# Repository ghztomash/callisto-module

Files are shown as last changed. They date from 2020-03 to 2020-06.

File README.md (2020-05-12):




# callisto-module
Callisto Eurorack Module.

A Teensy 3.2 based eurorack audio synth module.
Although the original idea was a Drum Synthesis module, the hardware is designed in a general way to support any audio synthesis firmware using the Teensy Audio Library.

A Hardware Abstraction Library is provided to simplify reading of the hardware peripherals.

## Features
* 1 x Trigger input with LED.
* 1 x CV 1 V/Oct input.
* 5 x -5 to +5 V CV inputs.
* 1 x 12bit DAC output.
* 6 x Potentiometers.
* 2 x Mode buttons with 3 LEDs each.

## Specs
* 10 HP Width
* 0.068% THD @ 100 Hz (But loads of noise from DSP ;))
* 9.6 Vpp output.
* +12V: 80 mA, -12V: 7 mA, +5V: 0 mA

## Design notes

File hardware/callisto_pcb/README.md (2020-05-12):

# callisto-module hardware
Callisto Eurorack module PCB Altium Designer files.
For Gerbers, schematics and BOM refer to the [Wiki](https://github.com/ghztomash/callisto-module/wiki) and [Release](https://github.com/ghztomash/callisto-module/releases) pages.

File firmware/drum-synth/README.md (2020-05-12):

### Drum voice synthesizer Firmware

Callisto Drum synthesizer, featuring 3 modes for kick, snare and hat sounds. With 3 waveforms each.

#### Parameters
* Pitch.
* Decay.
* Modulation Depth, bipolar, left envelope, right LFO.
* Modulation Rate, Envelope decay and LFO speed.
* DJ style filter, bipolar low-pass and high-pass.
* Overdrive.
* Instrument Select mode.
* Waveform Select mode.

#### Layout
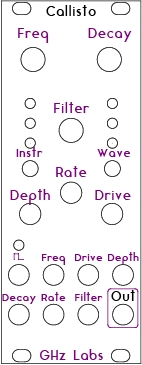
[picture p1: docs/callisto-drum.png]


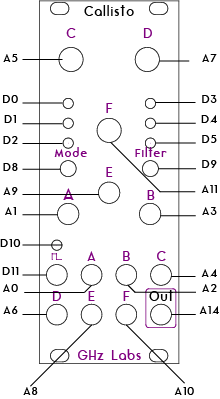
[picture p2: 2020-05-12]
docs/callisto-pinout.png

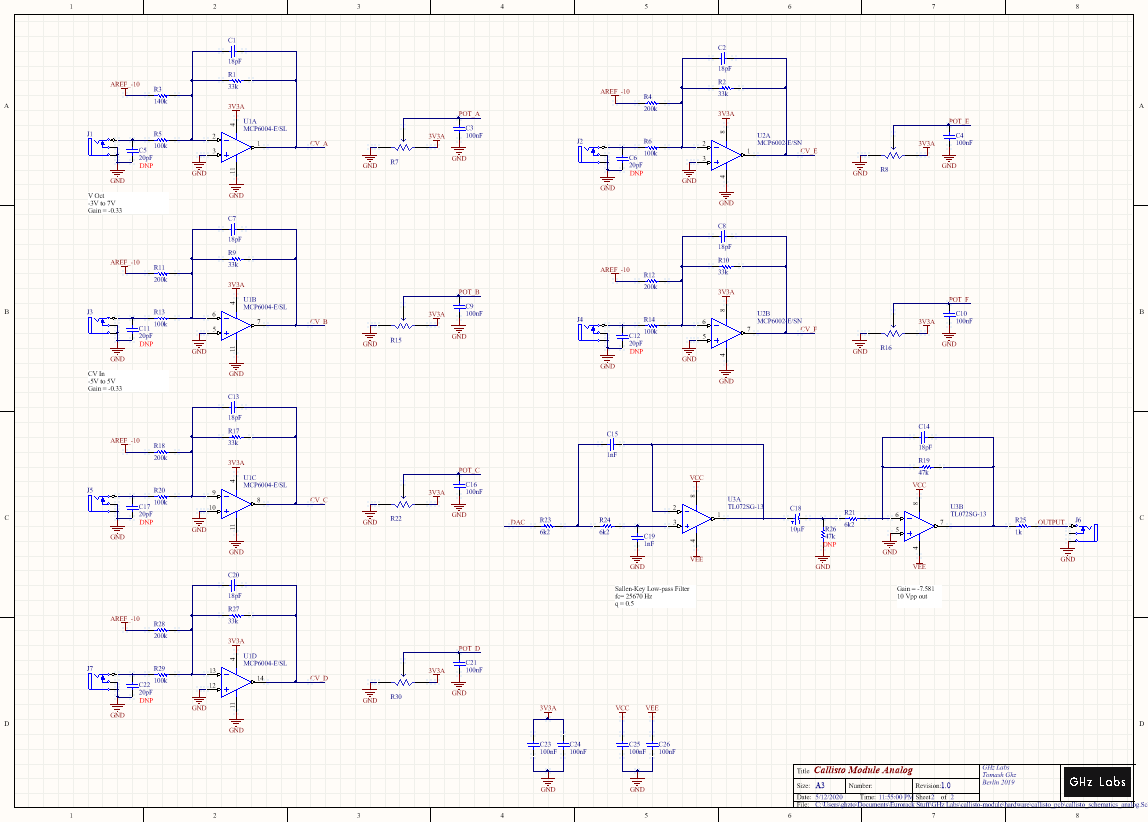
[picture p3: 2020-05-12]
docs/callisto-schematics.png

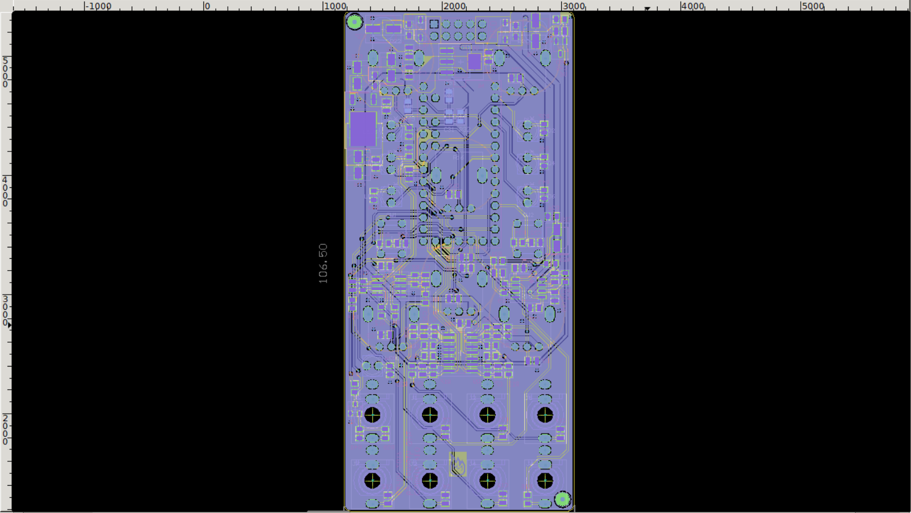
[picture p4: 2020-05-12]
docs/callisto-gerbers.png

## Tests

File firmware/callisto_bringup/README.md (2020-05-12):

## Bringup Firmware

Firmware to test all hardware capabilities and ADC calibration.

### CLI commands
* `cal` run calibration.
* `save` save calibration to EEPROM.
* `load` reload calibration from EEPROM.
* `res` reset calibration to default.
* `amp` output amplitude from 0.0 to 1.0.
* `freq` output sinwave frequency.
* `size` sampling statistics size for calibration.
* `avr` ADC averaging setting.
* `bit` ADC bithdepth setting.
* `ref` set target voltage for ADC input offset.

### Usage
Use a VT100 compatible terminal, like TeraTerm set to 115200 Baud and CR + LF transmission.

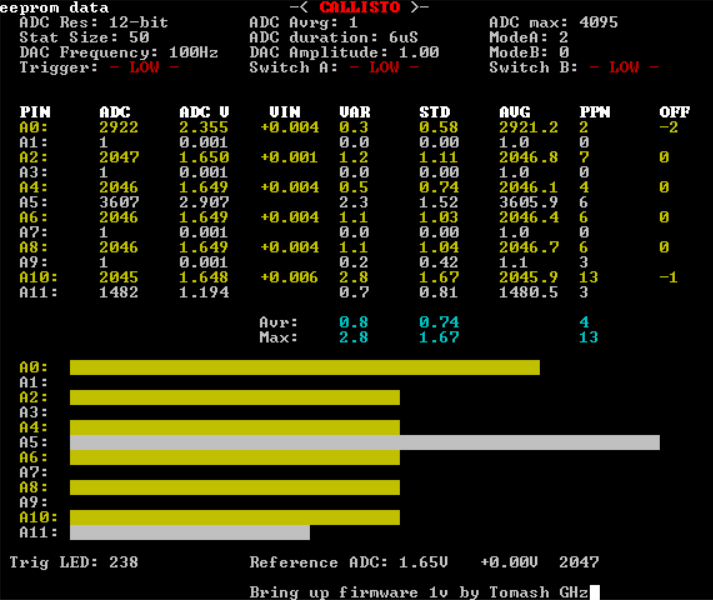
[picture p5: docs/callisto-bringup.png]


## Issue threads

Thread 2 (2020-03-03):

:sparkles: **Welcome to GitHub Projects** :sparkles:

ghztomash, 2020-03-03:
We're so excited that you've decided to create a new project! Now that you're here, let's make sure you know how to get the most out of GitHub Projects.
- [x] Create a new project
- [x] Give your project a name
- [ ] Press the <kbd>?</kbd> key to see available keyboard shortcuts
- [ ] Add a new column
- [x] Drag and drop this card to the new column
- [ ] Search for and add issues or PRs to your project
- [ ] Manage automation on columns
- [ ] [Archive a card](https://help.github.com/articles/archiving-cards-on-a-project-board/) or archive all cards in a column

Closed 2020-03-03.

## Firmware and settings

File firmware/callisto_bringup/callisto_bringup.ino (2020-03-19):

/* Callisto Eurorack Module - Bringup Firmware
 * Copyright (c) 2019 Tomash Ghz
 *
 * Please support GHz Labs and open-source hardware by purchasing
 * products directly from GHz Labs, donating or becoming a Github Sponsor!
 * 
 * MIT License
 *
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
 * THE SOFTWARE IS PROVIDED "AS IS", WITHOUT WARRANTY OF ANY KIND, EXPRESS OR
 * IMPLIED, INCLUDING BUT NOT LIMITED TO THE WARRANTIES OF MERCHANTABILITY,
 * FITNESS FOR A PARTICULAR PURPOSE AND NONINFRINGEMENT. IN NO EVENT SHALL THE
 * AUTHORS OR COPYRIGHT HOLDERS BE LIABLE FOR ANY CLAIM, DAMAGES OR OTHER
 * LIABILITY, WHETHER IN AN ACTION OF CONTRACT, TORT OR OTHERWISE, ARISING FROM,
 * OUT OF OR IN CONNECTION WITH THE SOFTWARE OR THE USE OR OTHER DEALINGS IN THE
 * SOFTWARE.
 */
 
#include <Audio.h>
#include <EEPROM.h>
#include "vt100.h"

#define VERSION 1

// PIN defines
#define LEDA 0
#define LEDB 1
#define LEDC 2
#define LEDD 3
#define LEDE 4
#define LEDF 5
#define LEDTRIG 10

#define SWITCHA 8
#define SWITCHB 9

#define TRIGIN 11

#define CVA	A0
#define POTA A1
#define CVB	A2
#define POTB A3
#define CVC	A4
#define POTC A5
#define CVD	A6
#define POTD A7
#define CVE	A8
#define POTE A9
#define CVF	A10
#define POTF A11

// Audio Objects
AudioSynthWaveformSine			osc1;
AudioSynthWaveform				osc2;
AudioAnalyzeRMS					rms1;
AudioOutputAnalog				out1;
AudioConnection					patchCordrms(osc2, 0, rms1, 0);
AudioConnection					patchCordout(osc1, 0, out1, 0);

// Global Variables
int trig = 0;
int lastTrig = 0;

int currentModeA = 5;
int currentModeB = 0;

bool modeButtonA = LOW;
bool lastModeButtonA = LOW;
bool modeButtonB = LOW;
bool lastModeButtonB = LOW;

int ADC_RESOLUTION = 12;
int ADC_AVERAGING = 1;
int SAMPLES = 50;	// 5000

int MAXADC = (1 << ADC_RESOLUTION) - 1;	// maximum possible reading from ADC
float VREF = 3.3;		// ADC reference voltage (= power supply)
float VINPUT = 1.65;	// ADC input voltage from Normalized Jack			
int EXPECTED = MAXADC*(VINPUT/VREF);	// expected ADC reading
float VINPUTVOCT = 2.357;	// ADC input voltage from Normalized Jack 
int EXPECTEDVOCT = MAXADC*(VINPUTVOCT/VREF);	// expected ADC reading

int ledsPins[6] = {LEDA, LEDB, LEDC, LEDD, LEDE, LEDF};
int ledsStates[6] = {0};
int trigLedState = 0;

int adcPins[12] = {CVA, POTA, CVB, POTB, CVC, POTC, CVD, POTD, CVE, POTE, CVF, POTF};
int adcVal[12] = {0};
int adcCalibration[12] = {0}; // calibration table;
int adcOffset[12] = {0}; // offset table;
//uint32_t adcSum[12] = {0};

float frequency[] = {100, 1000, 10000};
float amplitude[] = {0.0, 0.5, 1.0};

char inString[124];

long oldT;
long durT;

enum CLI_COMMAND {
	CLI_ERR,
	CLI_REF,
	CLI_AMP,
	CLI_FREQ,
	CLI_CAL,
	CLI_SAVE,
	CLI_LOAD,
	CLI_SIZE,
	CLI_BIT,
	CLI_AVR,
	CLI_RES
};

struct EepromData {
	int config;
	int version;
	int calibration[12];
};

void setup() {

	for (int i=0; i<6; i++){
		pinMode(ledsPins[i], OUTPUT);
		digitalWrite(ledsPins[i], HIGH);
		delay(100);
	}
	for (int i=0; i<6; i++){
		digitalWrite(ledsPins[i], LOW);
		delay(100);
	}
	pinMode(LEDTRIG, OUTPUT);
	digitalWrite(LEDTRIG, HIGH);
	
	pinMode(TRIGIN, INPUT_PULLUP);
	pinMode(SWITCHA, INPUT_PULLUP);
	pinMode(SWITCHB, INPUT_PULLUP);
	
	digitalWrite(ledsPins[currentModeA], HIGH);
	digitalWrite(ledsPins[currentModeB], HIGH);
	
	analogReference(EXTERNAL);
	analogReadResolution(ADC_RESOLUTION);
	analogReadAveraging(ADC_AVERAGING);
	
	//setup PWM for LED
	analogWriteResolution(8);
	analogWriteFrequency(LEDTRIG, 187500);
	
	AudioMemory(64);
	//osc1.begin(WAVEFORM_SINE);
	osc1.frequency(frequency[0]);
	osc1.amplitude(amplitude[2]);
	osc2.begin(1.0, 0.25, WAVEFORM_SINE);
	
	inString[0]='\0';
	
	loadEeprom();
	
}

void loop() {
	
	int tab = 0;

	modeButtonA = digitalRead(SWITCHA);
	
	if(modeButtonA != lastModeButtonA){
		if(modeButtonA == LOW){
			digitalWrite(ledsPins[currentModeA], LOW);
			currentModeA++;
			if(currentModeA >= 6)
				currentModeA = 3;
			digitalWrite(ledsPins[currentModeA], HIGH);
			osc1.amplitude(amplitude[currentModeA-3]);
		}
	lastModeButtonA = modeButtonA;
	}
	
	modeButtonB = digitalRead(SWITCHB);
	
	if(modeButtonB != lastModeButtonB){
		if(modeButtonB == LOW){
			digitalWrite(ledsPins[currentModeB], LOW);
			currentModeB++;
			if(currentModeB >= 3)
				currentModeB = 0;
			digitalWrite(ledsPins[currentModeB], HIGH);
			osc1.frequency(frequency[currentModeB]);
		}
	lastModeButtonB = modeButtonB;
	}
	
	trig = digitalRead(TRIGIN);
	if(trig != lastTrig){
		if(trig == LOW){
			
		}
	lastTrig = trig;
	}
	
	//printClear();
	//setCursor(1,1);
	
	//drawRow(1,1,30,205);
	//drawRow(1,44,30,205);
	//drawBox(TABLE_SETUP,1,74,4);
	setCursor(TABLE_SETUP+1,3);
	print("ADC Res: ");
	print(ADC_RESOLUTION);
	print("-bit");
	setCursor(TABLE_SETUP+1,26);
	print("ADC Avrg: ");
	print(ADC_AVERAGING);
	setCursor(TABLE_SETUP+1,50);
	print("ADC max: ");
	print(MAXADC);
	
	setCursor(TABLE_SETUP+2,3);
	eraseLine();
	print("Stat Size: ");
	print(SAMPLES);
	setCursor(TABLE_SETUP+2,26);
	print("ADC duration: ");
	print((int)durT);
	print("uS");
	setCursor(TABLE_SETUP+2,50);
	print("ModeA: ");
	print(currentModeA-3);
	
	setCursor(TABLE_SETUP+3,3);
	eraseLine();
	print("DAC Frequency: ");
	print(frequency[currentModeB],0);
	print("Hz");
	setCursor(TABLE_SETUP+3,26);
	print("DAC Amplitude: ");
	print(amplitude[currentModeA-3]);
	setCursor(TABLE_SETUP+3,50);
	print("ModeB: ");
	print(currentModeB);
	
	setCursor(TABLE_SETUP+4,3);
	eraseLine();
	print("Trigger: ");
	print(HIGHLOW(!trig));
	setCursor(TABLE_SETUP+4,26);
	print("Switch A: ");
	print(HIGHLOW(!modeButtonA));
	setCursor(TABLE_SETUP+4,50);
	print("Switch B: ");
	print(HIGHLOW(!modeButtonB));
	
	//drawBox(TABLE_SETUP,1,74,4);
	//drawBox(TABLE_ADC,1,74,13);
	//drawBox(TABLE_GRAPH,1,74,12);
	if(!DRAWCSV){
		tab=3;
		setCursor(TABLE_ADC+1,tab);
		printColor(VTBOLD,VTWHITE, VTBLACK);
		print("PIN");
		tab+=TAB_INCREMENT;
		setCursor(TABLE_ADC+1,tab);
		print("ADC");
		tab+=TAB_INCREMENT;
		setCursor(TABLE_ADC+1,tab);
		print("ADC V");
		tab+=TAB_INCREMENT;
		setCursor(TABLE_ADC+1,tab);
		print(" VIN");
		tab+=TAB_INCREMENT;
		setCursor(TABLE_ADC+1,tab);
		print("VAR");
		tab+=TAB_INCREMENT;
		setCursor(TABLE_ADC+1,tab);
		print("STD");
		tab+=TAB_INCREMENT;
		setCursor(TABLE_ADC+1,tab);
		print("AVG");
		tab+=TAB_INCREMENT;
		setCursor(TABLE_ADC+1,tab);
		print("PPN");
		tab+=TAB_INCREMENT;
		setCursor(TABLE_ADC+1,tab);
		print("OFF");
	} else {
		tab=3;
		setCursor(TABLE_ADC+1,tab);
		resetColor();
		print("PIN, ");
		tab+=TAB_INCREMENT;
		setCursor(TABLE_ADC+1,tab);
		print("ADC, ");
		tab+=TAB_INCREMENT;
		setCursor(TABLE_ADC+1,tab);
		print("VAR, ");
		tab+=TAB_INCREMENT;
		setCursor(TABLE_ADC+1,tab);
		print("STD, ");
		tab+=TAB_INCREMENT;
		setCursor(TABLE_ADC+1,tab);
		print("AVG, ");
		tab+=TAB_INCREMENT;
		setCursor(TABLE_ADC+1,tab);
		print("PPN");
	}
	//cursorForward(6);
	resetColor();
	println();
	
	float maxVariance = 0;
	float maxSTD = 0;
	int maxPPN = 0;
	float avrVariance = 0;
	float avrSTD = 0;
	int avrPPN = 0;

	for (int i=0; i<12; i++ ){
		
		delay(5);
		
		oldT = micros();
		adcVal[i] = analogRead(adcPins[i]) - adcCalibration[i]; // callibration offset
		durT = micros() - oldT;
		
		long datSum = 0;	// reset our accumulated sum of input values to zero
			int sMax = 0;
			int sMin = MAXADC;
			long n;						// count of how many readings so far
			double x,mean,delta,m2,variance,stdev;	// to calculate standard deviation
		
			n = 0;		 // have not made any ADC readings yet
			mean = 0; // start off with running mean at zero
			m2 = 0;
		
		
		for (int j=0; j<SAMPLES; j++) {
				x = analogRead(adcPins[i]) - adcCalibration[i]; // callibration offset
				datSum += x;
				if (x > sMax) sMax = x;
				if (x < sMin) sMin = x;
				n++;
				delta = x - mean;
				mean += delta/n;
				m2 += (delta * (x - mean));
			}
		
		variance = m2/(n-1);	// (n-1):Sample Variance	(n): Population Variance
			stdev = sqrt(variance);	// Calculate standard deviation
		float datAvg = (1.0*datSum)/n;
		int ppNoise = sMax - sMin;
		
		if (ppNoise > maxPPN)
		maxPPN = ppNoise;
		if ( stdev > maxSTD)
		maxSTD = stdev;
		if (variance > maxVariance)
			maxVariance = variance;
		avrPPN += ppNoise;
		avrSTD +=stdev;
		avrVariance +=variance;
		
		int sOffset;
		
		if(i==0) // for 1v/oct input
		sOffset = datAvg - EXPECTEDVOCT;
		else
		sOffset = datAvg - EXPECTED;
	
		adcOffset[i] = sOffset;
		
		if(i%2==0)
		printColor(VTNORMAL,VTYELLOW,VTBLACK);
		else
		resetColor();
		if (!DRAWCSV) {
			tab=3;
			setCursor(TABLE_ADC+2+i, tab);
			eraseLine();
			print("A");
			print(i);
			print(":");
			tab+=TAB_INCREMENT;
			setCursor(TABLE_ADC+2+i, tab);
			print(adcVal[i]);
			tab+=TAB_INCREMENT;
			setCursor(TABLE_ADC+2+i, tab);
			print((adcVal[i]/(float)MAXADC)*3.3, 3);
			tab+=TAB_INCREMENT;
			setCursor(TABLE_ADC+2+i, tab);
			if(i==0) // for 1v/oct input
			print(((adcVal[i]/(float)MAXADC)*3.3)/-0.33+7.14, 3, 1);
			else if(i%2==0)
			print(((adcVal[i]/(float)MAXADC)*3.3)/-0.33+5, 3, 1);
			tab+=TAB_INCREMENT;
			setCursor(TABLE_ADC+2+i, tab);
			print((float)variance,1);
			tab+=TAB_INCREMENT;
			setCursor(TABLE_ADC+2+i, tab);
			print((float)stdev);
			tab+=TAB_INCREMENT;
			setCursor(TABLE_ADC+2+i, tab);
			print((float)datAvg,1);
			tab+=TAB_INCREMENT;
			setCursor(TABLE_ADC+2+i, tab);
			print((int)ppNoise);
			tab+=TAB_INCREMENT;
			setCursor(TABLE_ADC+2+i, tab);
			if(i%2==0)
			print((int)sOffset);
			
			tab=3;
			setCursor(TABLE_GRAPH+1+i, tab);
			eraseLine();
			print("A");
			print(i);
			print(":");
			
			drawRow(TABLE_GRAPH+1+i, 8,(adcVal[i]/(float)MAXADC)*67, 219 );
		} else {
			tab=3;
			setCursor(TABLE_ADC+2+i, tab);
			eraseLine();
			print("A");
			print(i);
			print(":, ");
			tab+=TAB_INCREMENT;
			setCursor(TABLE_ADC+2+i, tab);
			print(adcVal[i]);
			print(", ");
			tab+=TAB_INCREMENT;
			setCursor(TABLE_ADC+2+i, tab);
			print((float)variance,1);
			print(", ");
			tab+=TAB_INCREMENT;
			setCursor(TABLE_ADC+2+i, tab);
			print((float)stdev);
			print(", ");
			tab+=TAB_INCREMENT;
			setCursor(TABLE_ADC+2+i, tab);
			print((float)datAvg,1);
			print(", ");
			tab+=TAB_INCREMENT;
			setCursor(TABLE_ADC+2+i, tab);
			print((int)ppNoise);
			print("\n");
		}
	}
	
	// print stats for all ADC pins
	avrPPN /= 12;
	avrSTD /= 12.0;
	avrVariance /= 12.0;
	
	setCursor(TABLE_GRAPH-2, 3 + TAB_INCREMENT * 3);
	eraseLine();
	print("Avr:");
	setCursor(TABLE_GRAPH-1, 3 + TAB_INCREMENT * 3);
	eraseLine();
	print("Max:");
	printColor(VTNORMAL,VTCYAN,VTBLACK);
	setCursor(TABLE_GRAPH-1, 3 + TAB_INCREMENT * 4);
	print((float)maxVariance, 1);
	setCursor(TABLE_GRAPH-1, 3 + TAB_INCREMENT * 5);
	print((float)maxSTD);
	setCursor(TABLE_GRAPH-1, 3 + TAB_INCREMENT * 7);
	print(maxPPN);
	
	setCursor(TABLE_GRAPH-2, 3 + TAB_INCREMENT * 4);
	print((float)avrVariance, 1);
	setCursor(TABLE_GRAPH-2, 3 + TAB_INCREMENT * 5);
	print((float)avrSTD);
	setCursor(TABLE_GRAPH-2, 3 + TAB_INCREMENT * 7);
	print(avrPPN);
	
	resetColor();
	
	//print CSV values
	
	//drawBox(TABLE_SETUP,1,74,4);
	//drawBox(TABLE_ADC,1,74,13);
	//drawBox(TABLE_GRAPH,1,74,12);
	
	setCursor(TABLE_SETUP,30);
	//eraseLine();
	print("-<");
	printColor(VTBOLD,random(1,7),VTBLACK);
	print(" CALLISTO "); //14
	resetColor();
	print(">-");
	
	setCursor(TABLE_GRAPH+14,2);
	eraseLine();
	
	if(rms1.available()){
	float rms = rms1.read();
	print("Trig LED: ");
	print(rms* 255, 0);
	analogWrite(LEDTRIG, rms * 255);
	}
	
	setCursor(TABLE_GRAPH+14,26);
	print("Reference ADC: ");
	print(VINPUT);
	print("V\t");
	print(VINPUT/-0.33+5,2,1);
	print("V\t");
	print(EXPECTED);
	
	println();
	
	if(strlen(inString)>1){
	print(">>> ");
	print(inString);
	}
	
	while(Serial.available()){
	char inByte = Serial.read();
	if(inByte == '\n'){
		parseCommand();
		inString[0]='\0';
	} else {
		sprintf(inString, "%s%c", inString, inByte);
	}
	}
	
	setCursor(TABLE_GRAPH+16,26);
	print("Bring up firmware 1v by Tomash GHz");
	
	printWrite();
	
	delay(10);
	
}

float linToExp(float index, float range){
	//convert linear values to exponential
	float ratio = pow(range, 1/(float)range);
	return pow(ratio,index);
}

void parseCommand(){
	char * pch;
	pch = strtok (inString," ,");
	//println();
	uint8_t command = CLI_COMMAND::CLI_ERR;
	uint8_t arguments = 0;
	
	while (pch != NULL)
	{
		//print(pch);
		
		if (strncmp (pch,"ref",3) == 0)
		{
			print(" found\n");
			command = CLI_COMMAND::CLI_REF;
		} else if (strncmp (pch,"amp",3) == 0)
		{
			print(" found\n");
			command = CLI_COMMAND::CLI_AMP;
		} else if (strncmp (pch,"freq",3) == 0)
		{
			print(" found\n");
			command = CLI_COMMAND::CLI_FREQ;
		} else if (strncmp (pch,"cal",3) == 0)
		{
			print(" found\n");
			command = CLI_COMMAND::CLI_CAL;
			// callibrate 
			for (int i=0; i<12; i++ ){
			if(i%2==0){
				adcCalibration[i] = adcOffset[i];
			}
			}
		}
		else if (strncmp (pch,"save",3) == 0)
		{
			print(" found\n");
			command = CLI_COMMAND::CLI_SAVE;
			saveEeprom();
		} else if (strncmp (pch,"load",3) == 0)
		{
			print(" found\n");
			command = CLI_COMMAND::CLI_LOAD;
			loadEeprom();
		} else if (strncmp (pch,"size",3) == 0)
		{
			print(" found\n");
			command = CLI_COMMAND::CLI_SIZE;
		} else if (strncmp (pch,"bit",3) == 0)
		{
			print(" found\n");
			command = CLI_COMMAND::CLI_BIT;
		} else if (strncmp (pch,"avr",3) == 0)
		{
			print(" found\n");
			command = CLI_COMMAND::CLI_AVR;
		} else if (strncmp (pch,"res",3) == 0)
		{
			print(" found\n");
			command = CLI_COMMAND::CLI_RES;
			
			for (int i=0; i<12; i++ ){
				adcCalibration[i] = 0;
			}
		}
		
		if (arguments == 1){
			if(command == CLI_COMMAND::CLI_REF){
				float arg = atof(pch);
				if (arg>12.0)
					arg = 12.0;
				if (arg<-12.0)
					arg = -12.0;
				
				VINPUT = (arg*-0.33)+1.65;
				EXPECTED = MAXADC*(VINPUT/VREF);	// expected ADC reading
				
				VINPUTVOCT = (arg*-0.33)+2.357;
				EXPECTEDVOCT = MAXADC*(VINPUTVOCT/VREF);	// expected ADC reading
			} else if(command == CLI_COMMAND::CLI_AMP){
				float arg = atof(pch);
				if (arg>1.0)
					arg = 1.0;
				if (arg<0.0)
					arg = 0.0;
				
				amplitude[currentModeA-3] = arg;
				osc1.amplitude(amplitude[currentModeA-3]);
			} else if(command == CLI_COMMAND::CLI_FREQ){
				float arg = atof(pch);
				if (arg>20000.0)
					arg = 20000.0;
				if (arg<1.0)
					arg = 1.0;
				
				frequency[currentModeB] = arg;
				osc1.frequency(frequency[currentModeB]);
			} else if(command == CLI_COMMAND::CLI_SIZE){
				float arg = atof(pch);
				if (arg>5000.0)
					arg = 5000.0;
				if (arg<1.0)
					arg = 1.0;
				
				SAMPLES = arg;
			} else if(command == CLI_COMMAND::CLI_BIT){
				float arg = atof(pch);
				if (arg>13.0)
					arg = 13.0;
				if (arg<1.0)
					arg = 1.0;
				
				ADC_RESOLUTION = arg;
				MAXADC = (1 << ADC_RESOLUTION) - 1;
				analogReadResolution(ADC_RESOLUTION);
				
				EXPECTED = MAXADC*(VINPUT/VREF);	// expected ADC reading
				EXPECTEDVOCT = MAXADC*(VINPUTVOCT/VREF);
			} else if(command == CLI_COMMAND::CLI_AVR){
				float arg = atof(pch);
				if (arg>32.0)
					arg = 32.0;
				if (arg<1.0)
					arg = 1.0;
				
				ADC_AVERAGING = arg;
				analogReadAveraging(ADC_AVERAGING);
			}
		} 
		
		pch = strtok (NULL, " ,");
		arguments++;
	}
	//println();
}

void saveEeprom(){
	int eeAddress = 0;
	EepromData eedata = { 0xDEAD, VERSION, {0}};
	
	for (int i=0; i<12; i++ ){
		eedata.calibration[i] = adcCalibration[i];
	}
	
	EEPROM.put(eeAddress, eedata);
}

void loadEeprom(){
	int eeAddress = 0;
	EepromData eedata;
	EEPROM.get(eeAddress, eedata);
	
	if(eedata.config == 0xDEAD){
		print("eeprom data\n");
		for (int i=0; i<12; i++ ){
			adcCalibration[i] = eedata.calibration[i];
		}
	} else {
		print("no data\n");
	}
}

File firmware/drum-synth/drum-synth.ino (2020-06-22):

/* Callisto Eurorack Module - Drum Synth Firmware
 * Copyright (c) 2020 Tomash Ghz
 *
 * Please support GHz Labs and open-source hardware by purchasing
 * products directly from GHz Labs, donating or becoming a Github Sponsor!
 * 
 * MIT License
 *
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
 * THE SOFTWARE IS PROVIDED "AS IS", WITHOUT WARRANTY OF ANY KIND, EXPRESS OR
 * IMPLIED, INCLUDING BUT NOT LIMITED TO THE WARRANTIES OF MERCHANTABILITY,
 * FITNESS FOR A PARTICULAR PURPOSE AND NONINFRINGEMENT. IN NO EVENT SHALL THE
 * AUTHORS OR COPYRIGHT HOLDERS BE LIABLE FOR ANY CLAIM, DAMAGES OR OTHER
 * LIABILITY, WHETHER IN AN ACTION OF CONTRACT, TORT OR OTHERWISE, ARISING FROM,
 * OUT OF OR IN CONNECTION WITH THE SOFTWARE OR THE USE OR OTHER DEALINGS IN THE
 * SOFTWARE.
 */

#include <Audio.h>
#include "callisto_hal.h"
#include "envelope_ar.h"
#include "play_memory_sample.h"
#include "filter_variable.h"
#include "synth_waveform.h"

#include "AudioSampleCKick.h"
#include "AudioSampleCsnare.h"
#include "AudioSampleCclap.h"
#include "AudioSampleChat1.h"
#include "AudioSampleChat2.h"

#define HOLD_TRIGGER 0

// Audio Objects

AudioPlayMemorySample			sampleKick1;
AudioPlayMemorySample			sampleSnare1;
AudioPlayMemorySample			sampleSnare2;
AudioPlayMemorySample			sampleHat1;
AudioPlayMemorySample			sampleHat2;

AudioFilterStateVariableGhz		vcfKick1;

AudioSynthWaveformDc			dcMod1;
AudioSynthWaveformModulatedGhz	lfoMod1;
AudioEnvelopeAR					egMod1;
AudioMixer4						modmix1;

AudioSynthWaveformModulatedGhz	osc1;
AudioSynthWaveformModulatedGhz	osc2;
AudioSynthWaveformModulatedGhz	osc3;
AudioSynthWaveformModulatedGhz	osc4;

AudioSynthWaveformDc			dc2;

AudioSynthNoisePink				noise1;
AudioFilterStateVariableGhz		vcf_noise1; // filter

AudioMixer4						mixKick;
AudioMixer4						mixSnare;
AudioMixer4						mixHat;
AudioMixer4						mixMulti;
AudioMixer4						mixOSCNoise;
AudioMixer4						mixInstrument;

AudioMixer4						mixShaper;
AudioEffectWaveshaper			waveshaper;

AudioEnvelopeAR					eg1;
AudioEnvelopeAR					egSnare1;
AudioFilterStateVariableGhz		vcf1; // main filter
AudioFilterStateVariableGhz		vcf2; // main filter

AudioMixer4						mixMaster; // master mixer
AudioAmplifier					inverter; // invert waveform to have the correct phase (inverting opamp configuration)
AudioAnalyzeRMS					rms1; // RMS analyzer for LED indicator

AudioOutputAnalog				out1;

// Audio Object connections

AudioConnection					patchCordMulti1(osc1, 0, mixMulti, 0);
AudioConnection					patchCordMulti2(osc2, 0, mixMulti, 1);
AudioConnection					patchCordMulti3(osc3, 0, mixMulti, 2);
AudioConnection					patchCordMulti4(osc4, 0, mixMulti, 3);

AudioConnection					patchCordKickMix1(osc1, 0, mixKick, 0);
AudioConnection					patchCordKickMix2(mixMulti, 0, mixKick, 1);
AudioConnection					patchCordKickMix3(sampleKick1, 0, mixKick, 2);
AudioConnection					patchCordKickMix4(mixKick, 0, vcfKick1, 0);

AudioConnection					patchCordNoise1(noise1, 0, vcf_noise1, 0);

AudioConnection					patchCordonSnare1(osc1, 0, egSnare1, 0);
AudioConnection					patchCordonSnare3(egSnare1, 0, mixOSCNoise, 0);
AudioConnection					patchCordonSnare4(vcf_noise1, 1, mixOSCNoise, 1);

AudioConnection					patchCordSnareMix1(mixOSCNoise, 0, mixSnare, 0);
AudioConnection					patchCordSnareMix2(sampleSnare1, 0, mixSnare, 1);
AudioConnection					patchCordSnareMix3(sampleSnare2, 0, mixSnare, 2);

AudioConnection					patchCordHatMix1(vcf_noise1, 2, mixHat, 0);
AudioConnection					patchCordHatMix2(sampleHat1, 0, mixHat, 1);
AudioConnection					patchCordHatMix3(sampleHat2, 0, mixHat, 2);

AudioConnection					patchCordInstMix1(vcfKick1, 0, mixInstrument, 0);
AudioConnection					patchCordInstMix2(mixSnare, 0, mixInstrument, 1);
AudioConnection					patchCordInstMix3(mixHat, 0, mixInstrument, 2);

AudioConnection					patchCordVca3(mixInstrument, 0, mixShaper, 0); 		// osc1 -> vca1
AudioConnection					patchCordVca4(mixShaper, 0, eg1, 0); 		// osc1 -> vca1

AudioConnection					patchCordVcf1(eg1, 0, vcf1, 0);		// vca1 -> vcf1
AudioConnection					patchCordVcf2(vcf1, 0, vcf2, 0); // DJ style Filter

// Modulation Sources
AudioConnection					patchCordfm1(dcMod1, 0, modmix1, 0);
AudioConnection					patchCordfm2(lfoMod1, 0, modmix1, 1);
AudioConnection					patchCordfm3(modmix1, 0, egMod1, 0);

AudioConnection					patchCordfm5(egMod1, 0, osc1, 0);			// osc1 frequency modulation
AudioConnection					patchCordfm6(egMod1, 0, osc2, 0);
AudioConnection					patchCordfm7(egMod1, 0, osc3, 0);
AudioConnection					patchCordfm8(egMod1, 0, osc4, 0);

AudioConnection					patchCordfm9(egMod1, 0, vcf_noise1, 1);
AudioConnection					patchCordfm9x(egMod1, 0, vcfKick1, 1);
AudioConnection					patchCordfm10(egMod1, 0, sampleKick1, 0);
AudioConnection					patchCordfm11(egMod1, 0, sampleSnare1, 0);
AudioConnection					patchCordfm12(egMod1, 0, sampleSnare2, 0);
AudioConnection					patchCordfm13(egMod1, 0, sampleHat1, 0);
AudioConnection					patchCordfm14(egMod1, 0, sampleHat2, 0);

AudioConnection					patchCordFilt2(vcf2, 2, mixMaster, 1);

AudioConnection					patchCordoutlrms(mixMaster, 0, rms1, 0);
AudioConnection					patchCordinv(mixMaster, 0, inverter, 0);
AudioConnection					patchCordout(inverter, 0, out1, 0);

float WAVESHAPE[] = {
  -0.964028, -0.941376, -0.905148, -0.848284, -0.761594, -0.635149, -0.462117, -0.244919, 
  0.000000,   0.244919, 0.462117, 0.635149, 0.761594, 0.848284, 0.905148, 0.941376, 0.964028
};

CallistoHAL callisto;

float frequency = 30;
float sampleSpeed = 1;
float cutoffLow = 30;
float cutoffHigh = 30;
float decay = 40;
float sourceMix = 0;
float depth = 0;
float rate = 0;
float width = 0;
float click = 0;
float cutoff = 0.7;
float frequencyHarmonics = 30;
float overdrive = 0;

volatile uint8_t trigger = 0;
uint32_t lastTrigger = 0;
volatile uint8_t lastMode = 0;
volatile uint8_t lastFilterMode = 0;
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

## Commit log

2019-07-26 pcb init
    [callisto_pcb.PrjPcb, callisto_schematics.SchDoc]
2019-07-26 teensy and power section
    [callisto_pcb.PrjPcb, callisto_schematics.SchDoc]
2019-07-31 Power Supply Schematics
    [callisto_schematics.SchDoc]
2019-08-02 Analog Section
    [callisto_pcb.PrjPcb, callisto_schematics.SchDoc, callisto_schematics_analog.SchDoc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]
2019-08-03 DAC output Section
    [callisto_schematics_analog.SchDoc, callisto_schematics_digital.SchDoc]
2019-08-04 Digital Section
    [callisto_schematics_analog.SchDoc, callisto_schematics_digital.SchDoc]
2019-08-05 PCB init
    Annotation and footprint fix
    PCB board initial
    [callisto_board.PcbDoc, callisto_pcb.PrjPcb, callisto_schematics_analog.SchDoc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]
2019-08-22 Preliminary component placement
    [callisto_pcb.PrjPcb, callisto_schematics_analog.SchDoc, callisto_schematics_digital.SchDoc]
2019-08-24 PCB Routing
2019-08-26 Output Job
    [callisto_panel.PcbDoc]
2019-08-26 Out Job
    [callisto_pcb.PrjPcb]
2019-09-03 DRC fixes
    [callisto_panel.PcbDoc, callisto_pcb.PrjPcb, callisto_schematics_analog.SchDoc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]
2019-10-30 Output file fix
    [callisto_panel.PcbDoc, callisto_pcb.PrjPcb]
2019-11-15 bringup firmware
    [callisto_schematics_analog.SchDoc]
2019-11-19 bringup firmware & BOM variant
    [callisto_pcb.PrjPcb, callisto_schematics_digital.SchDoc]
2020-02-09 Fixed formatting
    And moved few things
    [callisto_bringup.ino]
2020-03-04 Statistics for all ADC readings
2020-03-09 Updated function Prototypes, call back functions on mode change.
2020-03-10 Setter and Getter functions for switches, Trigger callback.
2020-03-12 Read ADC raw and normalized values for CV and Potentiometers
2020-03-12 Callibration Boot mode, reading ADC voltage
2020-03-12 Updated Bringup with 1v/oct ADC to Voltage reading
2020-03-15 One volt per octave input, LED PWM speed above audio range. Sinewave output for template.
2020-03-16 Formatting and minor bug fixes
    [callisto_bringup.ino]
2020-03-17 Refactoring setMode and callbacks. Callbacks for button presses and mode changes. Added function to change source of 1v/oct CV inputs.
2020-03-20 Duuh, didn't include the files
    [callisto_hal.h, drum-synth.ino]
2020-03-22 Inverted output phase, frequency modulation, phase reset for Drum Snyth firmware.
    [drum-synth.ino]
2020-03-26 Noise and Impulse transients.
    [drum-synth.ino]
2020-03-27 Lfo and envelope pitch modulation. Noise / VCO crossfade.
    [drum-synth.ino]
2020-04-03 Source / Filter sound design implementation
2020-04-05 Multi timbral oscillator mode
    [drum-synth.ino]
2020-04-06 Multi voice Oscillator modulation.
    [drum-synth.ino]
2020-04-07 Sample Players
2020-04-14 Refactoring sample player object.
2020-04-15 Sound patch and additional samples.
2020-04-15 DJ filter implementation
2020-04-16 inverted lfo frequency, decay update on trigger
    [drum-synth.ino]
2020-05-09 Potentiometer 3D models.
    [callisto_schematics_analog.SchDoc]
2020-05-11 Interpolation not improving noise
    [callisto_hal.h]
2020-05-11 Sample modulation depth increased
2020-05-11 Updated BOM
    [callisto_pcb.PrjPcb, callisto_schematics_analog.SchDoc, callisto_schematics_digital.SchDoc]
2020-05-12 Updated BOM file
    [callisto_pcb.PrjPcb]
2020-05-12 Readme Files
    [callisto_pcb.PrjPcb]
2020-05-21 New samples sound design and level balancing.
2020-06-22 Fixes filter noise and Moved Oscillator sync into project.
    [drum-synth.ino, filter_variable.cpp]
